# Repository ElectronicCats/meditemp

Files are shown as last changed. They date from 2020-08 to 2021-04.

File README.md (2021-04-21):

# MediTemp

## ¿Qué es?
MediTemp-C es una estación autónoma de medición de temperatura corporal, ideal para la presente situación de contingencia nacional y mundial. 
Con MediTemp-C se puede realizar un control de acceso a establecimientos comerciales, bares, restaurantes, etc. 

La estación realiza una medición de temperatura corporal de manera no invasiva y sin contacto con las personas por medio de su sensor infrarrojo, además de realizar un conteo y registro de los datos los cuales pueden ser consultados y/o descargados vía inalámbrica por medio de cualquier dispositivo móvil o computadora

## ¿Cómo funciona?
1. La persona llega a la estación MediTemp-C acercando la frente o la parte interna de la muñeca al sensor de temperatura. La estación cuenta con un sensor de distancia indicando que tan cerca se debe de estar para una correcta medición.

2. Una vez realizada la medición de temperatura la estación muestra la temperatura de la persona por medio de una pantalla alfanumérica y guardará un registro el cual consiste en un conteo de personas, el valor medido de temperatura la fecha y la hora del registro. 

3. En caso de que se detecte a una persona con temperatura alta, la estación emitirá una alarma audible y encenderá un indicador luminoso. 

4. MediTemp-C cuenta con salidas electrónicas las cuales pueden activar o desactivar chapas o cerraduras magnéticas en caso de ser requerido para permitir o no permitir el acceso a personas con alta temperatura.

5. La estación muestra el conteo de personas que han ingresado en su pantalla y como aditamento adicional MediTemp-C cuenta con un contador de personas de salida, con lo cual se puede mostrar el número de personas que hay dentro del establecimiento

6. El registro de datos puede ser descargado vía inalámbrica por medio de cualquier teléfono móvil o computadora. también puede ser consultado vía internet desde cualquier parte del mundo. 

## Funcionalidades

Sensor de temperatura corporal 
Infrarrojo de no contacto
Pantalla alfanumérica para visualización de datos
Alarma audible Buzzer de 90dB 
Leds Indicadores grandes de 10mm brillantes 
Memoria SD para almacenamiento de datos
Conectividad WiFi 
2 salidas a relevador 
Tensión de contacto 220 VCD, 250 VAC. 
Corriente soportada 1A. 
Potencia 30W, 37.7 VA
Voltaje de trabajo 110 - 220 Vac 

## Caracteristicas Físicas

Estructura metálica a base de aluminio, medidas 20x20x5 cm. Lo cual proporciona alta duración y bajo peso (2kg). 
Puede ser Instalado en pared o con pedestal para piso con sujeción.
Compartimento para despachador de gel antibacterial.

## Aditamentos Adicionales

### Activación de cargas
MediTemp-C cuenta con dos salidas de relevador las cuales pueden ser usadas para la activación de puertas, chapas, cerraduras magnéticas, luminarias, u otros dispositivos. 

### Contador de personas de salida
La estación cuenta con la posibilidad de conectar un contador de personas de salida, el cual consiste en dos barras paralelas con sensores electrónicos compatible con la estación MediTemp-C. De esta forma, en la pantalla se mostrará el número de personas que hay en el momento en el  establecimiento.

# Licence

Electronic Cats invests time and resources providing this open source design, please support Electronic Cats and open-source hardware by purchasing products from Electronic Cats!

Designed by Electronic Cats.

Firmware released under an GNU AGPL v3.0 license. See the LICENSE file for more information.

Hardware released under an CERN Open Hardware Licence v1.2. See the LICENSE_HARDWARE file for more information.

Electronic Cats is a registered trademark, please do not use if you sell these PCBs.

November 2019

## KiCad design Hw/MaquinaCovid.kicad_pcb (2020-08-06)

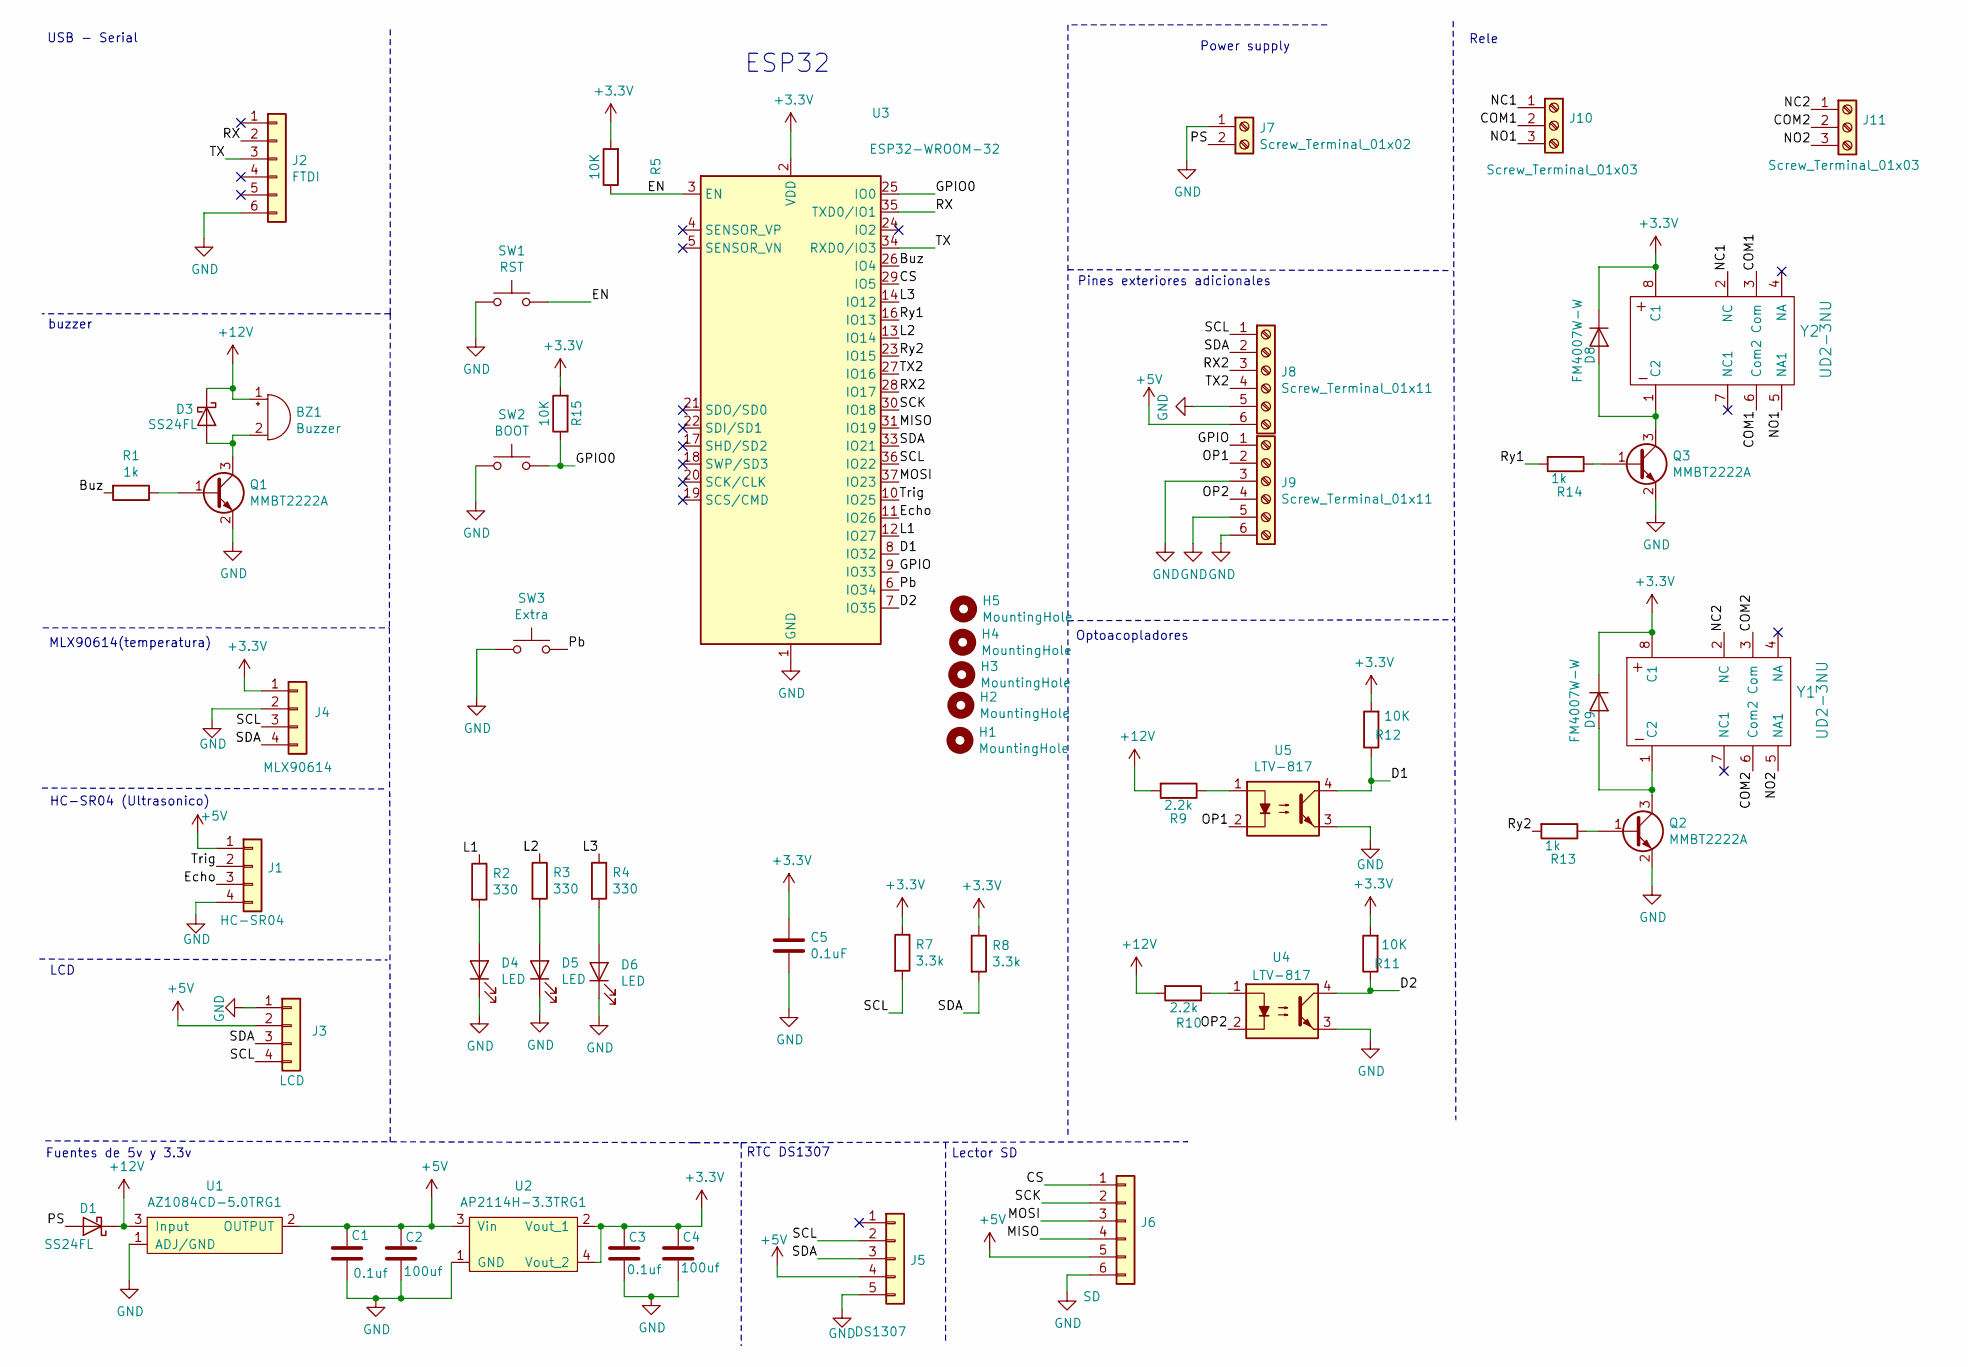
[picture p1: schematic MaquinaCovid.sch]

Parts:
BZ1: Buzzer
C1, C3: 0.1uf; C_0805_2012Metric_Pad1.15x1.40mm_HandSolder
C2, C4: 100uf; CP_EIA-3216-18_Kemet-A_Pad1.58x1.35mm_HandSolder
C5: 0.1uF; C_0805_2012Metric_Pad1.15x1.40mm_HandSolder
D1, D3: SS24FL; D_SOD-123F
D4, D5, D6: LED; PinHeader_1x02_P2.54mm_Vertical
D8, D9: FM4007W-W; F4007
H1, H2, H3, H4, H5: MountingHole; MountingHole_3.2mm_M3_Pad_Via
J1: HC-SR04; PinHeader_1x04_P2.54mm_Vertical
J2: FTDI; PinHeader_1x06_P2.54mm_Vertical
J3: LCD; PinHeader_1x04_P2.54mm_Vertical
J4: MLX90614; PinHeader_1x04_P2.54mm_Vertical
J5: DS1307; PinHeader_1x05_P2.54mm_Vertical
J6: SD; PinHeader_1x06_P2.54mm_Vertical
J7: Screw_Terminal_01x02; TerminalBlock_bornier-2_P5.08mm
J8, J9: Screw_Terminal_01x11; TerminalBlock_bornier-6_P5.08mm
J10, J11: Screw_Terminal_01x03; TerminalBlock_bornier-3_P5.08mm
Q1, Q2, Q3: MMBT2222A; SOT-23
R1, R13, R14: 1k; R_0805_2012Metric_Pad1.15x1.40mm_HandSolder
R2, R3, R4: 330; R_0805_2012Metric_Pad1.15x1.40mm_HandSolder
R5, R11, R12, R15: 10K; R_0805_2012Metric_Pad1.15x1.40mm_HandSolder
R7, R8: 3.3k; R_0805_2012Metric_Pad1.15x1.40mm_HandSolder
R9, R10: 2.2k; R_0805_2012Metric_Pad1.15x1.40mm_HandSolder
SW1: RST; SW_SPST_TL3342
SW2: BOOT; SW_SPST_TL3342
SW3: Extra; SW_SPST_TL3342
U1: AZ1084CD-5.0TRG1; TO-252-2
U2: AP2114H-3.3TRG1; SOT-223
U3: ESP32-WROOM-32
U4, U5: LTV-817; DIP-4_W7.62mm_Socket
Y1, Y2: UD2-3NU

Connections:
+3V3: C3.1, C4.1, C5.1, D8.1 (K), D9.1 (K), J4.1, R5.2, R7.1, R8.1, R11.2, R12.2, R15.2, U2.2 (Vout_1), U2.4 (Vout_2), U3.2 (VDD), Y1.8 (C1), Y2.8 (C1)
+5V: C1.1, C2.1, J1.1, J3.2, J5.4, J6.5, J8.6, U1.2 (OUTPUT), U2.3 (Vin)
+12V: BZ1.1 (-), D1.1 (K), D3.1 (K), R9.2, R10.2, U1.3 (Input)
/Buz: R1.2, U3.26 (IO4)
/COM1: J10.2, Y2.3 (Com), Y2.6 (Com2)
/COM2: J11.2, Y1.3 (Com), Y1.6 (Com2)
/CS: J6.1, U3.29 (IO5)
/D1: R12.1, U3.8 (IO32), U5.4
/D2: R11.1, U3.7 (IO35), U4.4
/EN: R5.1, SW1.2, U3.3 (EN)
/Echo: J1.3, U3.11 (IO26)
/GPIO: J9.1, U3.9 (IO33)
/GPIO0: R15.1, SW2.2, U3.25 (IO0)
/L1: R2.1, U3.12 (IO27)
/L2: R3.1, U3.13 (IO14)
/L3: R4.1, U3.14 (IO12)
/MISO: J6.4, U3.31 (IO19)
/MOSI: J6.3, U3.37 (IO23)
/NC1: J10.1, Y2.2 (NC)
/NC2: J11.1, Y1.2 (NC)
/NO1: J10.3, Y2.5 (NA1)
/NO2: J11.3, Y1.5 (NA1)
/OP1: J9.2, U5.2
/OP2: J9.4, U4.2
/PS: D1.2 (A), J7.2
/Pb: SW3.2, U3.6 (IO34)
/RX: J2.2, U3.35 (TXD0/IO1)
/RX2: J8.3, U3.28 (IO17)
/Ry1: R14.2, U3.16 (IO13)
/Ry2: R13.2, U3.23 (IO15)
/SCK: J6.2, U3.30 (IO18)
/SCL: J3.4, J4.3, J5.2, J8.1, R7.2, U3.36 (IO22)
/SDA: J3.3, J4.4, J5.3, J8.2, R8.2, U3.33 (IO21)
/TX: J2.3, U3.34 (RXD0/IO3)
/TX2: J8.4, U3.27 (IO16)
/Trig: J1.2, U3.10 (IO25)
GND: C1.2, C2.2, C3.2, C4.2, C5.2, D4.1 (K), D5.1 (K), D6.1 (K), J1.4, J2.6, J3.1, J4.2, J5.5, J6.6, J7.1, J8.5, J9.3, J9.5, J9.6, Q1.2 (E), Q2.2 (E), Q3.2 (E), SW1.1, SW2.1, SW3.1, U1.1 (ADJ/GND), U2.1 (GND), U3.1 (GND), U3.15 (GND), U3.38 (GND), U3.39 (GND), U4.3, U5.3
unnamed: BZ1.2 (+), D3.2 (A), Q1.3 (C)
unnamed: D4.2 (A), R2.2
unnamed: D5.2 (A), R3.2
unnamed: D6.2 (A), R4.2
unnamed: D8.2 (A), Q3.3 (C), Y2.1 (C2)
unnamed: D9.2 (A), Q2.3 (C), Y1.1 (C2)
unnamed: Q1.1 (B), R1.1
unnamed: Q2.1 (B), R13.1
unnamed: Q3.1 (B), R14.1
unnamed: R9.1, U5.1
unnamed: R10.1, U4.1

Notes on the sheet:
Fuentes de 5v y 3.3v
MLX90614(temperatura)
HC-SR04 (Ultrasonico)
LCD
buzzer
USB - Serial
ESP32
RTC DS1307
Lector SD
Power supply
Rele
Pines exteriores adicionales
Optoacopladores

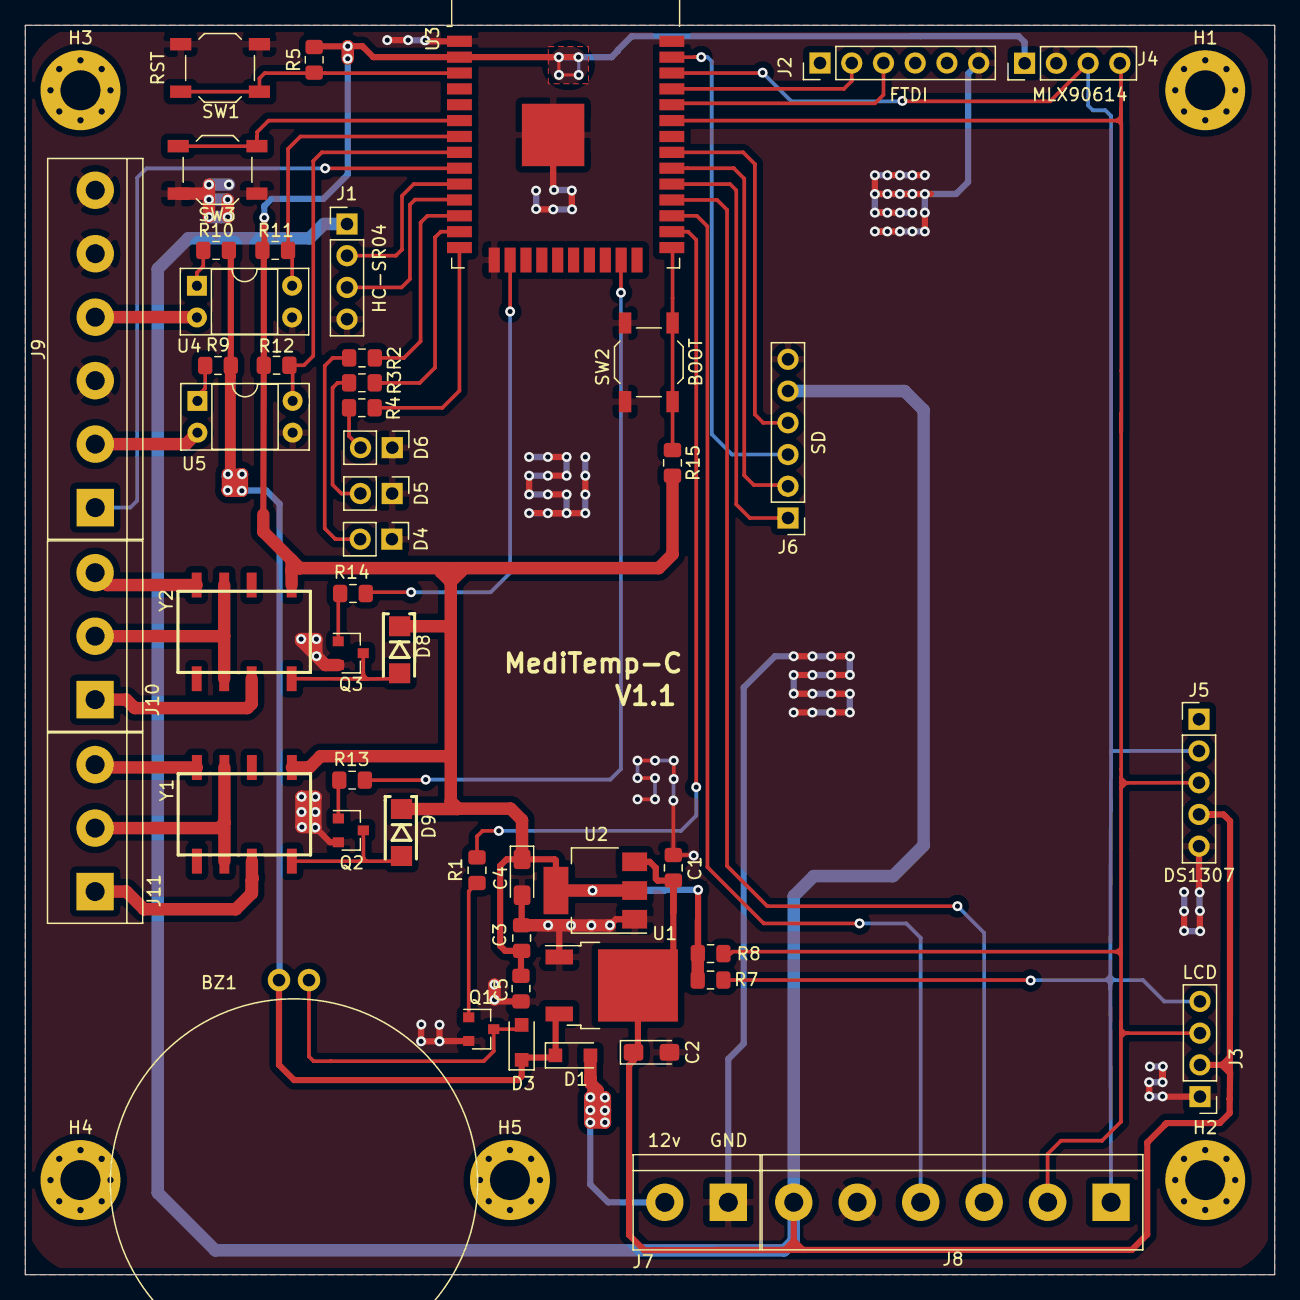
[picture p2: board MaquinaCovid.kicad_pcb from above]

Board: 2 copper layers, 100.0 x 100.0 mm, 56 parts (0 on the bottom side), 48 nets.

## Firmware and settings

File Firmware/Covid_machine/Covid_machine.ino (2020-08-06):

/**********************************************************
  This example code works for Covid Machine
  
  Created by Andres Sabas @ Electronic Cats 2020
  Jorge Uri @ Electronic Cats

  Electronic Cats 2020
*************************************************************/
#include <LiquidCrystal_I2C.h>
#include <Wire.h>
#include <Adafruit_MLX90614.h>
#include "Wire.h"
#include "FS.h" // Libraries for SD card
#include "SD.h"
#include <SPI.h>
#include <IotWebConf.h>

// -- Initial name of the Thing. Used e.g. as SSID of the own Access Point.
const char thingName[] = "TempC";

// -- Initial password to connect to the Thing, when it creates an own Access Point.
const char wifiInitialApPassword[] = "smrtTHNG8266";

// -- Configuration specific key. The value should be modified if config structure was changed.
#define CONFIG_VERSION "dem1"

// -- When CONFIG_PIN is pulled to ground on startup, the Thing will use the initial
//      password to buld an AP. (E.g. in case of lost password)
#define CONFIG_PIN 34

// -- Status indicator pin.
//      First it will light up (kept LOW), on Wifi connection it will blink,
//      when connected to the Wifi it will turn off (kept HIGH).
#define STATUS_PIN LED_BUILTIN

DNSServer dnsServer;
WebServer server(80);
HTTPUpdateServer httpUpdater;

IotWebConf iotWebConf(thingName, &dnsServer, &server, wifiInitialApPassword, CONFIG_VERSION);

#define DS3231_I2C_ADDRESS 0x68

int counter = 0;
//defines temperature global variables
float temperaturaObjeto;

// defines pins numbers of ultrasonic
const int trigPin = 25;
const int echoPin = 26;
String memoria = "";
String tiempo = "";
// defines variables of ultrasonic
long duration;
int distance;
// set the LCD number of columns and rows
int lcdColumns = 16;
int lcdRows = 2;
// set LCD address, number of columns and rows
// if you don't know your display address, run an I2C scanner sketch
LiquidCrystal_I2C lcd(0x3F, lcdColumns, lcdRows);
// Instanciar objeto (TEMP)
Adafruit_MLX90614 termometroIR = Adafruit_MLX90614();


void createDir(fs::FS &fs, const char * path);
void removeDir(fs::FS &fs, const char * path);
void readFile(fs::FS &fs, const char * path);
void writeFile(fs::FS &fs, const char * path, const char * message);
void appendFile(fs::FS &fs, const char * path, const char * message);
void renameFile(fs::FS &fs, const char * path1, const char * path2);
void deleteFile(fs::FS &fs, const char * path);
void testFileIO(fs::FS &fs, const char * path);
byte decToBcd(byte val);
byte bcdToDec(byte val);
void setDS3231time(byte second, byte minute, byte hour, byte dayOfWeek, byte dayOfMonth, byte month, byte year);
void readDS3231time(byte *second, byte *minute, byte *hour, byte *dayOfWeek, byte *dayOfMonth, byte *month, byte *year);

void setup()
{
  Serial.begin(9600);
  
  iotWebConf.setStatusPin(STATUS_PIN);
  iotWebConf.setConfigPin(CONFIG_PIN);
  iotWebConf.setupUpdateServer(&httpUpdater);

  // -- Initializing the configuration.
  iotWebConf.init();

  // -- Set up required URL handlers on the web server.
  server.on("/", handleRoot);
  server.on("/config", []{ iotWebConf.handleConfig(); });
  server.onNotFound([](){ iotWebConf.handleNotFound(); });

  
  Wire.begin();
  
  // set the initial time here:
  // DS3231 seconds, minutes, hours, day, date, month, year
  setDS3231time(1, 6, 13, 2, 3, 8, 20); // Cambiar esto siempre que se inicialice
  pinMode(trigPin, OUTPUT); // Sets the trigPin as an Output
  pinMode(echoPin, INPUT); // Sets the echoPin as an Input
  pinMode(12, OUTPUT);
  pinMode(14, OUTPUT);
  pinMode(33, OUTPUT);
  // initialize LCD
  lcd.init();
  // turn on LCD backlight
  lcd.backlight();
  // Iniciar termómetro infrarrojo con Arduino
  termometroIR.begin();
  pantalla();

  if (!SD.begin()) {
    Serial.println("Card Mount Failed");
    return;
  }
  uint8_t cardType = SD.cardType();

  if (cardType == CARD_NONE) {
    Serial.println("No SD card attached");
    return;
  }

  Serial.print("SD Card Type: ");
  if (cardType == CARD_MMC) {
    Serial.println("MMC");
  } else if (cardType == CARD_SD) {
    Serial.println("SDSC");
  } else if (cardType == CARD_SDHC) {
    Serial.println("SDHC");
  } else {
    Serial.println("UNKNOWN");
  }
  appendFile(SD, "/Cliente.csv", "Temperatura,Hora,Fecha,Val,\n");
  /*
      listDir(SD, "/", 0);
      createDir(SD, "/mydir");
      listDir(SD, "/", 0);
      removeDir(SD, "/mydir");
      listDir(SD, "/", 2);
      writeFile(SD, "/Cliente.csv", "Cliente ");
      appendFile(SD, "/Cliente.csv", "World!\n");
      readFile(SD, "/Cliente.csv");
      deleteFile(SD, "/foo.csv");
      renameFile(SD, "/Cliente.csv", "/foo.csv");
      readFile(SD, "/foo.csv");
      testFileIO(SD, "/test.csv");
      Serial.printf("Total space: %lluMB\n", SD.totalBytes() / (1024 * 1024));
      Serial.printf("Used space: %lluMB\n", SD.usedBytes() / (1024 * 1024));
  */

}


void loop()
{

  // Clears the trigPin
  digitalWrite(trigPin, LOW);
  delayMicroseconds(2);
  // Sets the trigPin on HIGH state for 10 micro seconds
  digitalWrite(trigPin, HIGH);
  delayMicroseconds(10);
  digitalWrite(trigPin, LOW);
  // Reads the echoPin, returns the sound wave travel time in microseconds
  duration = pulseIn(echoPin, HIGH);
  // Calculating the distance
  distance = duration * 0.034 / 2;
  // Prints the distance on the Serial Monitor
  Serial.print("Distance: ");
  Serial.println(distance);
  delay(200);
  if (distance <= 7)
  {
    counter ++;
    temperatura();
  }

  // -- doLoop should be called as frequently as possible.
  iotWebConf.doLoop();
}


void pantalla()
{
  // initialize LCD
  lcd.init();
  // turn on LCD backlight
  lcd.backlight();
  // set cursor to first column, first row
  lcd.setCursor(0, 1);
  lcd.clear();
  lcd.setCursor(0, 0);
  lcd.clear();
  // print message
  lcd.print("Bienvenido");
  delay(1500);
  // clears the display to print new message
  lcd.clear();
  // set cursor to first column, second row
  lcd.print("Coloque sufrente");
  //delay(1000);
  lcd.setCursor(0, 1);
  lcd.print("abajo por favor");
  delay(1000);
  return;
}

void pantalla2()
{
  lcd.setCursor(0, 1);
  lcd.clear();
  lcd.setCursor(0, 0);
  lcd.clear();
  lcd.print("Temp ");
  lcd.print(temperaturaObjeto);
  lcd.setCursor(0, 1);
  lcd.print("Pase usted");
  delay(1000);
  return;
}

void pantalla3()
{
  lcd.setCursor(0, 1);
  lcd.clear();
  lcd.setCursor(0, 0);
  lcd.clear();
  lcd.print("Temp ");
  lcd.print(temperaturaObjeto);
  lcd.setCursor(0, 1);
  lcd.print("NO PASE");
  delay(1000);
  return;
}

void temperatura()
{
  // Obtener temperaturas grados Celsius
  float temperaturaAmbiente = termometroIR.readAmbientTempC();
  temperaturaObjeto = termometroIR.readObjectTempC();
  byte second, minute, hour, dayOfWeek, dayOfMonth, month, year;
  // retrieve data from DS3231
  readDS3231time(&second, &minute, &hour, &dayOfWeek, &dayOfMonth, &month, &year);
  // Mostrar información

  Serial.print("Temp. ambiente => ");
  Serial.print(temperaturaAmbiente);
  Serial.println("ºC");

  Serial.print("Temp. objeto => ");
  Serial.print(temperaturaObjeto);
  Serial.println("ºC");

  memoria += String(temperaturaObjeto);
  memoria += ",";
  tiempo += String(hour);
  tiempo += ":";
  if (minute < 10)
  {
    tiempo += "0";
  }
  tiempo += String(minute);
  tiempo += ":";
  if (second < 10)
  {
    tiempo += "0";
  }
  tiempo += String(second);
  tiempo += ",";
  if (dayOfMonth < 10)
  {
    tiempo += "0";
  }
  tiempo += String(dayOfMonth);
  tiempo += "/";
  if (month < 10)
  {
    tiempo += "0";
  }
  tiempo += String(month);
  tiempo += "/";
  tiempo += String(year);
  tiempo += ",";
  char datos[memoria.length() + 1];
  memoria.toCharArray(datos, memoria.length());
  char datost[tiempo.length() + 1];
  tiempo.toCharArray(datost, tiempo.length());
  appendFile(SD, "/Cliente.csv", datos);
  appendFile(SD, "/Cliente.csv", "C ");
  appendFile(SD, "/Cliente.csv", ",");
  appendFile(SD, "/Cliente.csv", datost);
  appendFile(SD, "/Cliente.csv", ",");
  memoria = "";
  tiempo = "";

  if (23 <= temperaturaObjeto && temperaturaObjeto <= 30)
  {
    digitalWrite(12, HIGH);   // turn the LED on (HIGH is the voltage level)
    pantalla2();
    delay(500);                       // wait for a second
    digitalWrite(12, LOW);    // turn the LED off by making the voltage LOW
    appendFile(SD, "/Cliente.csv", "Si");
  }
  else
  {
    digitalWrite(14, HIGH);   // turn the LED on (HIGH is the voltage level)
    digitalWrite(33, HIGH);
    pantalla3();
    delay(500);                       // wait for a second
    digitalWrite(14, LOW);    // turn the LED off by making the voltage LOW
    digitalWrite(33, LOW);
    appendFile(SD, "/Cliente.csv", "No");
  }
  appendFile(SD, "/Cliente.csv", "\n");
  readFile(SD, "/Cliente.csv");
  pantalla();
  return;

  // Si quieres mostrar la información en grados Fahrenheit utiliza las funciones
  // readAmbientTempF() para temperatura ambiente
  // readObjectTempF() para temperatura del objeto
}
void listDir(fs::FS &fs, const char * dirname, uint8_t levels) {
  Serial.printf("Listing directory: %s\n", dirname);

  File root = fs.open(dirname);
  if (!root) {
    Serial.println("Failed to open directory");
    return;
  }
  if (!root.isDirectory()) {
    Serial.println("Not a directory");
    return;
  }

  File file = root.openNextFile();
  while (file) {
    if (file.isDirectory()) {
      Serial.print("  DIR : ");
      Serial.println(file.name());
      if (levels) {
        listDir(fs, file.name(), levels - 1);
      }
    } else {
      Serial.print("  FILE: ");
      Serial.print(file.name());
      Serial.print("  SIZE: ");
      Serial.println(file.size());
    }
    file = root.openNextFile();
  }
}

void createDir(fs::FS &fs, const char * path) {
  Serial.printf("Creating Dir: %s\n", path);
  if (fs.mkdir(path)) {
    Serial.println("Dir created");
  } else {
    Serial.println("mkdir failed");
  }
}

void removeDir(fs::FS &fs, const char * path) {
  Serial.printf("Removing Dir: %s\n", path);
  if (fs.rmdir(path)) {
    Serial.println("Dir removed");
  } else {
    Serial.println("rmdir failed");
  }
}

void readFile(fs::FS &fs, const char * path) {
  Serial.printf("Reading file: %s\n", path);

  File file = fs.open(path);
  if (!file) {
    Serial.println("Failed to open file for reading");
    return;
  }

  Serial.print("Read from file: ");
  while (file.available()) {
    Serial.write(file.read());
  }
  file.close();
}

void writeFile(fs::FS &fs, const char * path, const char * message) {
  Serial.printf("Writing file: %s\n", path);

  File file = fs.open(path, FILE_WRITE);
  if (!file) {
    Serial.println("Failed to open file for writing");
    return;
  }
  if (file.print(message)) {
    Serial.println("File written");
  } else {
    Serial.println("Write failed");
  }
  file.close();
}

void appendFile(fs::FS &fs, const char * path, const char * message) {
  Serial.printf("Appending to file: %s\n", path);

  File file = fs.open(path, FILE_APPEND);
  if (!file) {
    Serial.println("Failed to open file for appending");
    return;
  }
  if (file.print(message)) {
    Serial.println("Message appended");
  } else {
    Serial.println("Append failed");
  }
  file.close();
}

void renameFile(fs::FS &fs, const char * path1, const char * path2) {
  Serial.printf("Renaming file %s to %s\n", path1, path2);
  if (fs.rename(path1, path2)) {
    Serial.println("File renamed");
  } else {
    Serial.println("Rename failed");
  }
}

void deleteFile(fs::FS &fs, const char * path) {
  Serial.printf("Deleting file: %s\n", path);
  if (fs.remove(path)) {
    Serial.println("File deleted");
  } else {
    Serial.println("Delete failed");
  }
}

void testFileIO(fs::FS &fs, const char * path) {
  File file = fs.open(path);
  static uint8_t buf[512];
  size_t len = 0;
  uint32_t start = millis();
  uint32_t end = start;
  if (file) {
    len = file.size();
    size_t flen = len;
    start = millis();
    while (len) {
      size_t toRead = len;
      if (toRead > 512) {
        toRead = 512;
      }
      file.read(buf, toRead);
      len -= toRead;
    }
    end = millis() - start;
    Serial.printf("%u bytes read for %u ms\n", flen, end);
    file.close();
  } else {
    Serial.println("Failed to open file for reading");
  }


  file = fs.open(path, FILE_WRITE);
  if (!file) {
    Serial.println("Failed to open file for writing");
    return;
  }

  size_t i;
  start = millis();
  for (i = 0; i < 2048; i++) {
    file.write(buf, 512);
  }
  end = millis() - start;
  Serial.printf("%u bytes written for %u ms\n", 2048 * 512, end);
  file.close();
}
byte decToBcd(byte val) {
  return ( (val / 10 * 16) + (val % 10) );
}
// Convert binary coded decimal to normal decimal numbers
byte bcdToDec(byte val) {

  return ( (val / 16 * 10) + (val % 16) );
}
void setDS3231time(byte second, byte minute, byte hour, byte dayOfWeek, byte dayOfMonth, byte month, byte year)
{
  // sets time and date data to DS3231
  Wire.beginTransmission(DS3231_I2C_ADDRESS);
  Wire.write(0); // set next input to start at the seconds register
  Wire.write(decToBcd(second)); // set seconds
  Wire.write(decToBcd(minute)); // set minutes
  Wire.write(decToBcd(hour)); // set hours
  Wire.write(decToBcd(dayOfWeek)); // set day of week (1=Sunday, 7=Saturday)
  Wire.write(decToBcd(dayOfMonth)); // set date (1 to 31)
  Wire.write(decToBcd(month)); // set month
  Wire.write(decToBcd(year)); // set year (0 to 99)
  Wire.endTransmission();
}
void readDS3231time(byte *second, byte *minute, byte *hour, byte *dayOfWeek, byte *dayOfMonth, byte *month, byte *year) {
  Wire.beginTransmission(DS3231_I2C_ADDRESS);
  Wire.write(0); // set DS3231 register pointer to 00h
  Wire.endTransmission();
  Wire.requestFrom(DS3231_I2C_ADDRESS, 7);
  // request seven bytes of data from DS3231 starting from register 00h
  *second = bcdToDec(Wire.read() & 0x7f);
  *minute = bcdToDec(Wire.read());
  *hour = bcdToDec(Wire.read() & 0x3f);
  *dayOfWeek = bcdToDec(Wire.read());
  *dayOfMonth = bcdToDec(Wire.read());
  *month = bcdToDec(Wire.read());
  *year = bcdToDec(Wire.read());
}

/**
 * Handle web requests to "/" path.
 */
void handleRoot()
{
  // -- Let IotWebConf test and handle captive portal requests.
  if (iotWebConf.handleCaptivePortal())
  {
    // -- Captive portal request were already served.
    return;
  }
  String s = "<!DOCTYPE html><html lang=\"en\"><head><meta name=\"viewport\" content=\"width=device-width, initial-scale=1, user-scalable=no\"/>";
  s += "<title>IotWebConf 04 Update Server</title></head><body>Hello world!";
  s += "Go to <a href='config'>configure page</a> to change values.";
  s += "</body></html>\n";

  server.send(200, "text/html", s);
}

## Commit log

2020-07-10 Add files via upload
    Schematic
    [MaquinaCovid.kicad_pcb, MaquinaCovid.sch]
2020-07-11 Finished schematic
    [MaquinaCovid.kicad_pcb, MaquinaCovid.sch]
2020-07-13 Schematic changes
    [MaquinaCovid.sch]
2020-07-14 Added led
    [MaquinaCovid.sch]
2020-07-15 Footprint placement (part 1)
    [MaquinaCovid.sch]
2020-07-16 Finished PCB
    [MaquinaCovid.kicad_pcb, MaquinaCovid.sch]
2020-07-16 Add v1.0
    [MaquinaCovid-B_Cu.gbr, MaquinaCovid-B_Mask.gbr, MaquinaCovid-B_Paste.gbr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]
2020-07-20 added sensor code
    I addded it on Hw to avoid conflicts with the firmware part
2020-07-21 add function temperature, lcd and others
2020-07-23 Integration of the sensors on the program
2020-08-05 More code
    SD and sensor code
2020-08-06 config OTA pin for extra button
2020-08-06 Covid machine V1.1
    -Added pull-up to the boot button
    -Change of the conection of the buzzer and relay pines
    -Added 5v to the ultrasonic sensor
    -Removed the diode on FTDI's TX pin
    -Added missing names on the componens
    [MaquinaCovid.kicad_pcb, MaquinaCovid.sch]
